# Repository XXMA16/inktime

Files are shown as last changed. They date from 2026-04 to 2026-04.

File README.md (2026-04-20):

# InkTime

## Overview

InkTime is an open-source smartwatch project that aims to provide a customizable and feature-rich wearable device,
powered by the Nordic nRF52840 SoC. The device is designed to be energy-efficient, featuring a 1.54-inch e-ink display,
a 250mAh battery, an IMU for motion tracking, and a haptic driver for tactile feedback.

## Hardware Diagram

Hardware Diagram

## Bill of Materials

| Quantity | Component | Package | Producer / Part | Link | Datasheet |
|---|---|---|---|---|---|
| 1 | SoC | aQFN-73 | Nordic / nRF52840-QIAA | [Link](TODO) | [Datasheet](TODO) |
| 1 | PMIC | BGA-8 | TI / BQ25180YBGR | [Link](TODO) | [Datasheet](TODO) |
| 1 | PMIC | WLCSP-15 | Richtek / RT6160AWSC | [Link](TODO) | [Datasheet](TODO) |
| 1 | Fuel Gauge IC | TDFN-8 | Analog Devices / MAX17048  | [Link](TODO) | [Datasheet](TODO) |
| 1 | ESD Protection IC | SOT-23-6 | ST / USBLC6-2SC6Y | [Link](TODO) | [Datasheet](TODO) |
| 1 | Haptic Driver | BGA-9 | TI / DRV2605YZFR | [Link](TODO) | [Datasheet](TODO) |
| 1 | IMU | 12-pin LGA | Bosch / BMA423 | [Link](TODO) | [Datasheet](TODO) |
| 1 | Antenna | 3216 (1206)  | Johanson / 2.45GHz Antenna | [Link](TODO) | [Datasheet](TODO) |
| 1 | Connector | FPC-24 | Molex / EPD Connector | [Link](TODO) | [Datasheet](TODO) |
| 1 | Connector | SMT | Kinghelm / KH-TYPE-C-16P | [Link](TODO) | [Datasheet](TODO) |
| 3 | Switch | SMT (Button) | Panasonic / Tactile SW | [Link](TODO) | [Datasheet](TODO) |
| 3 | Diode | SOD-123 | ON Semi / MBR0530 | [Link](TODO) | [Datasheet](TODO) |
| 1 | N-MOSFET | SC-70-3 | Vishay / SI1308EDL | [Link](TODO) | [Datasheet](TODO) |
| 1 | P-MOSFET | SOT-23 | Diodes Inc / DMG2305UX-7 | [Link](TODO) | [Datasheet](TODO) |

| Quantity | Component | Value | Package | Producer | Link | Datasheet |
|---|---|---|---|---|---|---|
| 1 | Jumper | - | SMD | - | [Link](TODO) | [Datasheet](TODO) |
| 3 | Resistor  | 0 | 0201 | - | [Link](TODO) | [Datasheet](TODO) |
| 1 | Resistor  | 0.47R | 0201 | - | [Link](TODO) | [Datasheet](TODO) |
| 1 | Resistor  | 2.2R | 0201 | - | [Link](TODO) | [Datasheet](TODO) |
| 2 | Resistor  | 3.3K | 0201 | - | [Link](TODO) | [Datasheet](TODO) |
| 2 | Resistor  | 5.1K | 0201 | - | [Link](TODO) | [Datasheet](TODO) |
| 6 | Resistor  | 10K | 0201 | - | [Link](TODO) | [Datasheet](TODO) |
| 3 | Capacitor | N.C. | 0201 | - | - | ** - |
| 2 | Capacitor | 1pF | 0201 | - | [Link](TODO) | [Datasheet](TODO) |
| 1 | Capacitor | 820pF | 0201 | - | [Link](TODO) | [Datasheet](TODO) |
| 4 | Capacitor | 12pF | 0201 | - | [Link](TODO) | [Datasheet](TODO) |
| 1 | Capacitor | 100pF | 0201 | - | [Link](TODO) | [Datasheet](TODO) |
| 1 | Capacitor | 47nF | 0201 | - | [Link](TODO) | [Datasheet](TODO) |
| 9 | Capacitor | 100nF | 0201 | - | [Link](TODO) | [Datasheet](TODO) |
| 1 | Capacitor | 0.1uF/50V | 0201 | - | [Link](TODO) | [Datasheet](TODO) |
| 7 | Capacitor | 1uF | 0402 | - | [Link](TODO) | [Datasheet](TODO) |
| 9 | Capacitor | 1uF/50V | 0402 | - | [Link](TODO) | [Datasheet](TODO) |
| 5 | Capacitor | 4.7uF | 0402 | - | [Link](TODO) | [Datasheet](TODO) |
| 1 | Capacitor | 4.7uF/25V | 0402 | - | [Link](TODO) | [Datasheet](TODO) |
| 3 | Capacitor | 10uF | 0402 | - | [Link](TODO) | [Datasheet](TODO) |
| 2 | Capacitor | 22uF | 0402 | - | [Link](TODO) | [Datasheet](TODO) |
| 1 | Inductor  | 3.9nH | 0402 | - | [Link](TODO) | [Datasheet](TODO) |
| 1 | Inductor  | 470nH | 1008 | Cjiang | [Link](https://jlcpcb.com/partdetail/6763488-FTC252012SR47MBCA/C5832368) | [Datasheet](https://jlc-prod-smt.oss-eu-central-1.aliyuncs.com/smtDataManualFile/8602848214240948224-C5832368.pdf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) |
| 1 | Inductor  | 10uH | 0402 | - | [Link](TODO) | [Datasheet](TODO) |
| 1 | Inductor  | 15uH | 0402 | - | [Link](TODO) | [Datasheet](TODO) |
| 1 | Inductor  | 68uH | 4848 | Wurth | [Link](TODO) | [Datasheet](https://www.we-online.com/components/products/datasheet/744043003.pdf) |
| 1 | Crystal | 32.768kHz | SMD | Nordic | [Link](TODO) | [Datasheet](TODO) |
| 1 | Crystal | 32MHz | SMD | Nordic | [Link](TODO) | [Datasheet](TODO) |

## SoC pin configuration

- **P$AD22 (SWO)** - connection to TP_SWO for debugging
- **P$AA24 (SWDCLK)** - connection for SWD, for the purpose of clock debugging
- **P$AC24 (SWDIO)** - SWD input/output connection
- **P$AC13 (RESET)** - connection to TP_RESET and SWD for resetting the component
- **P$Y23 (P1.01)** - E-Paper Drive Circuit
- **P$AD12 (EPD_BUSY)** - indicates whether the screen is busy displaying or not
- **P$AD10 (EPD_DC)** - E-Paper Display Data/Command selection for SPI connection
- **P$K2 (EPD_CS)** - E-Paper Display Chip Select (SPI)
- **P$AD12 (EPD_RST)** - E-Paper Display Reset for SPI connection
- **P$P13 (MOSI)** - data for screen SPI connection
- **P$A12 (SCK)** - clock for screen SPI connection
- **P$L1 (SDA)** - I2C data for PMIC, Fuel Gauge, IMU
- **P$M2 (SCL)** - I2C clock for PMIC, Fuel Gauge, IMU
- **P$AD8 (P0.13)** - GPIO for the up button.
- **P$AC9 (P0.14)** - GPIO for the middle button.
- **P$W24 (P1.02)** - GPIO for the down button.
- **P$AD6 (D+)** - positive differential trace to the ESD Protection
- **P$AD4 (D-)** - negative differential trace to the ESD Protection
- **P$AD2 (VBUS)** - connection to the VBUS signal of the USB-C Connector
- **P$U1 (HAPTIC_EN)** - Haptic Driver enable/disable
- **P$T2 (PMIC_INT)** - PMIC LiPo battery interrupt
- **P$N1 (IMU_INT1)** - IMU interrupt
- **P$P2 (IMU_INT2)** - IMU interrupt
- **P\$F2 & P$D2** - 32 kHz clock
- **P\$A23 & P$A24** - 32 MHz clock
- **P$J24 (ALERT)** - Fuel Gauge circuit alert
- **P\$H23 & P$F23** - wireless transmission via the antenna

## PCB Layout

### Stackup

1. Signal and Power
2. Ground Plane
3. Power
4. Signal

Thickness: 1mm

- solder mask: 0.0254mm
- surface finish: Hasl 0.02mm
- copper weight: 1oz
- layers: 0.035mm
- outer dielectrics: 0.128mm
- inner dielectric: 0.5132mm

Via Stitching

- drill: 0.35mm diameter
- spacing: 1.8mm
- offset: 0.6mm from the edge of the board

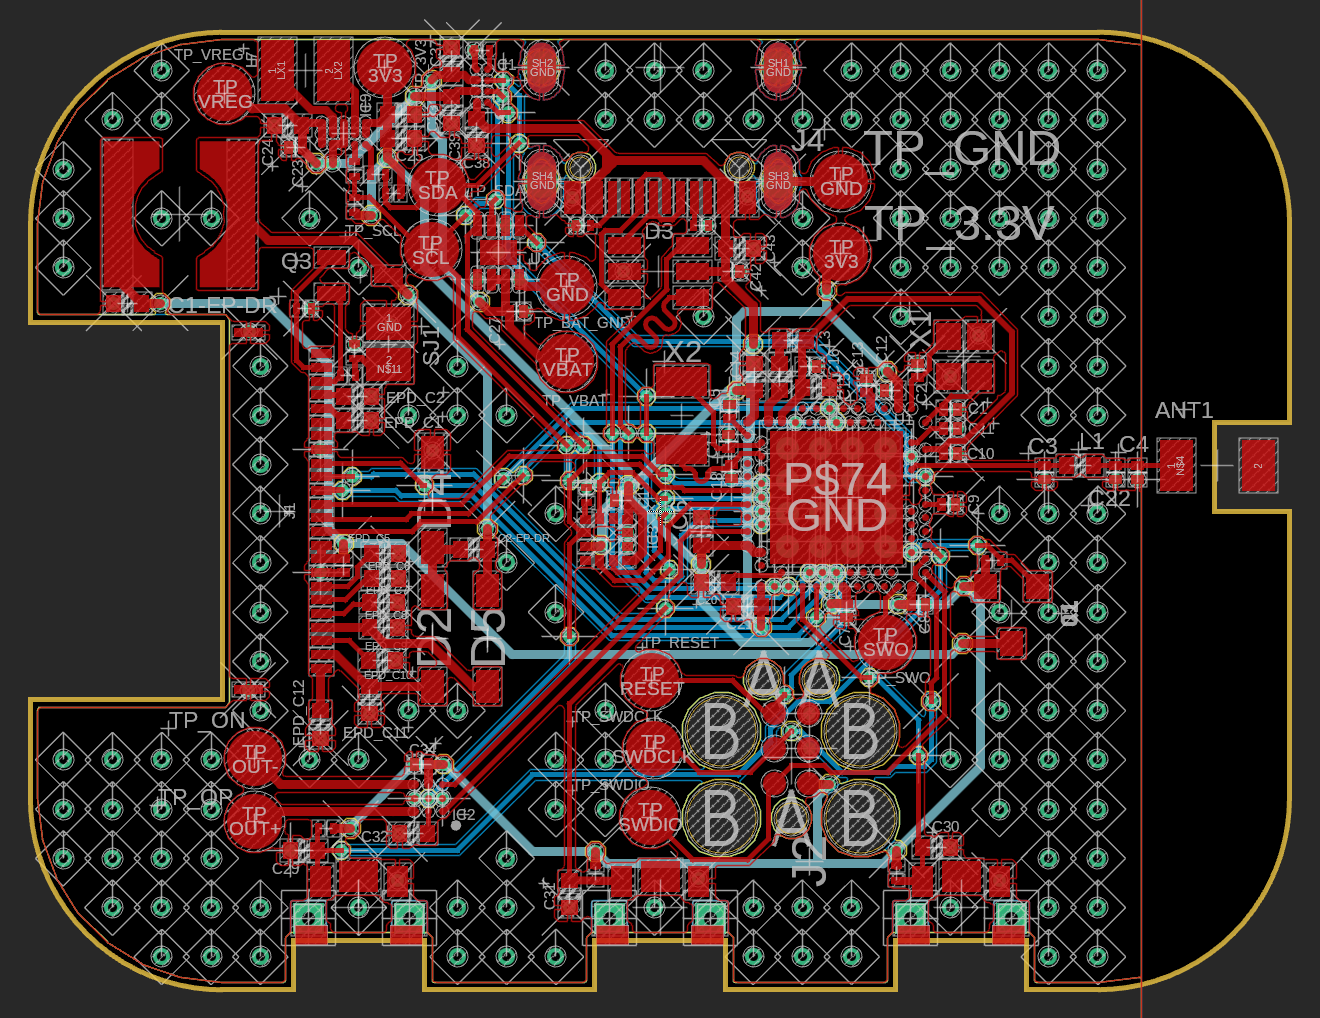
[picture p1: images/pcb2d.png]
PCB Layout


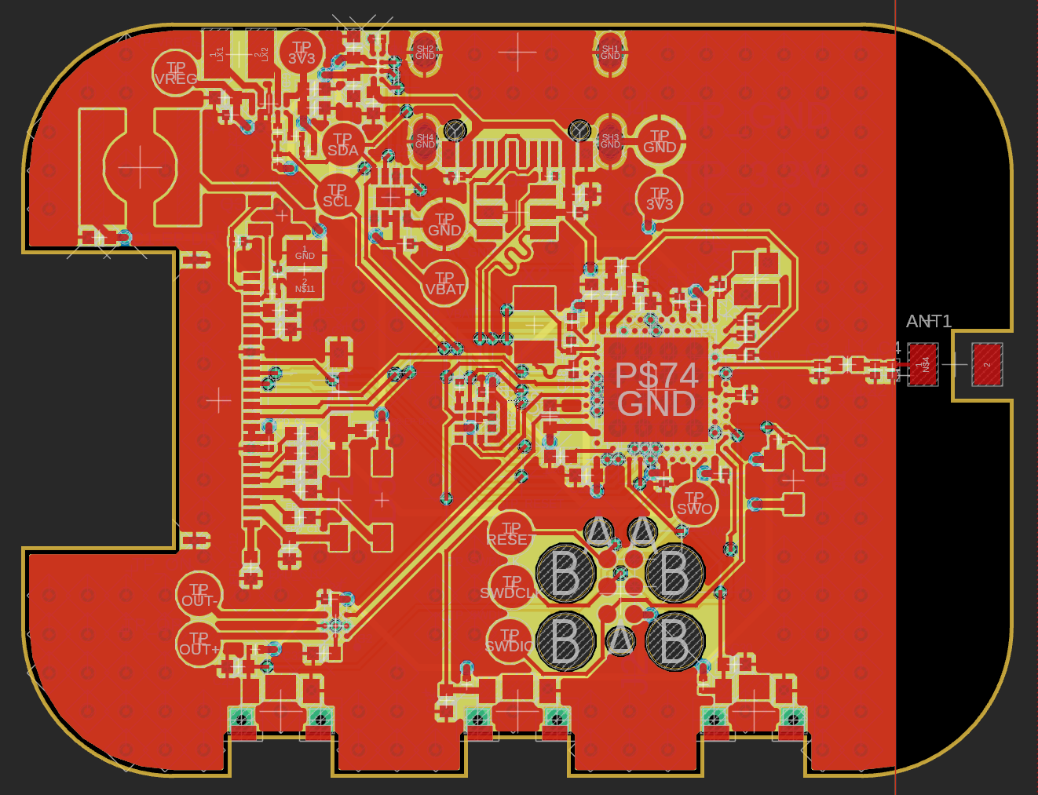
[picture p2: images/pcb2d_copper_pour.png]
PCB Layout Copper Pour


### Component Placement

The **antenna** is placed close to the right edge of the board, with a cutout in the copper pours on the entire right
side of the board. There is also a cutout in the PCB itself under the unconnected pad of the antenna.  
The **PI** network is placed as close as possible to the antenna, an additional capacitor may be placed to better tune
the antenna.  
Light propagates at around half its speed in a vacuum in FR4. A simple calculation gives a value of around:

$$\frac{\lambda}{4} = \frac{c_{FR4}}{4f} \approx \frac{1.4 \times 10^8 m/s}{4 \times 2.4 \times 10^9 Hz} \approx 14.6 mm$$

The trace connecting the PI network to the nRF52840 pin is 5mm long, thus the antenna should work properly.  
It would be better to use a grounded coplanar waveguide for the trace, maybe calculate the width using JLCPCB's online
calculator and use one of their layer stackups instead of the one described above, but this should suffice
for a first iteration of the board.

The decoupling capacitors are placed as possible to the power pins of the IC components and in between the power line
and the pin itself.  
The crystals are also placed close to the pins of the SoC, with the load capacitors traces matched in length and as
short as possible.  
The inductor for the E-Paper Drive Circuit is placed far from any signal lines to avoid interference, even though
it is in a shielded package.

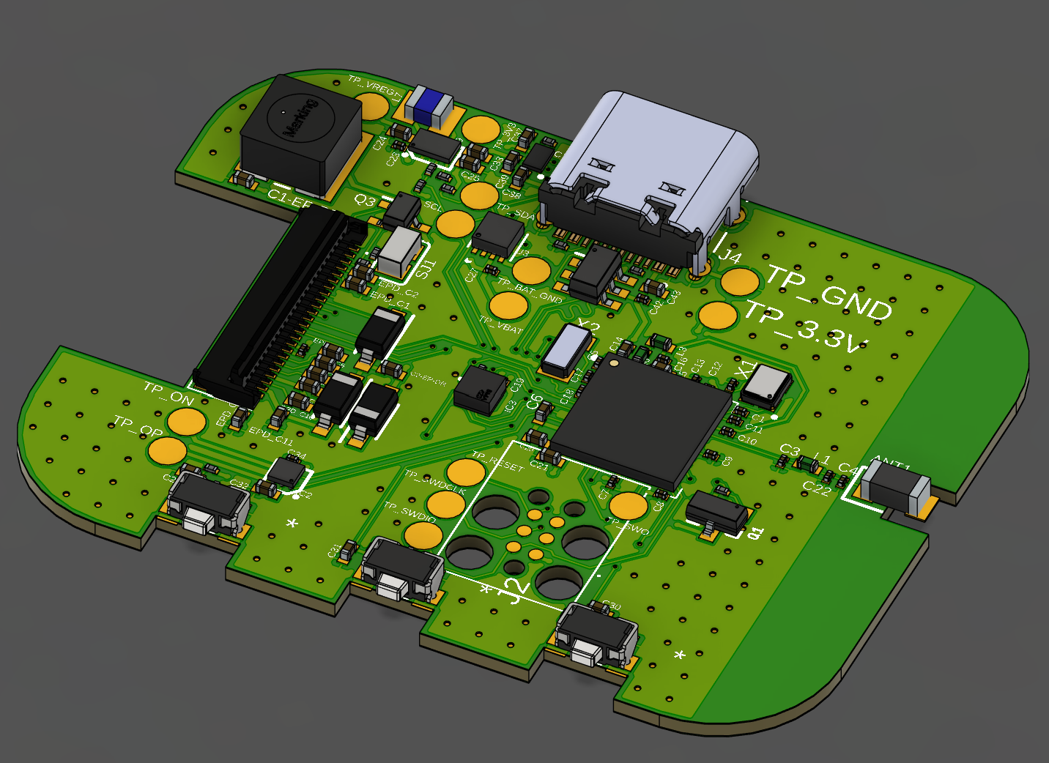
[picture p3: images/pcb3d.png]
PCB 3D Render


### Approved Errors

Most of the errors are related to drill sizes or blind to micro via ratios. These are all approved since, although it
will be more expensive to manufacture, JLCPCB is still able to drill the holes and make the vias.  
Thus these kind of errors can be safely ignored.

Since the nRF52840 is a BGA package, some of the pins *must* have vias in the pad. Some of these cause Fusion to give
a copper clearance error, but, again, JLCPCB is able to manufacture the board so they can also be approved.

## Mechanical Design

The buzzer is placed on the back of the board, in the lower left corner (when worn on the left wrist).

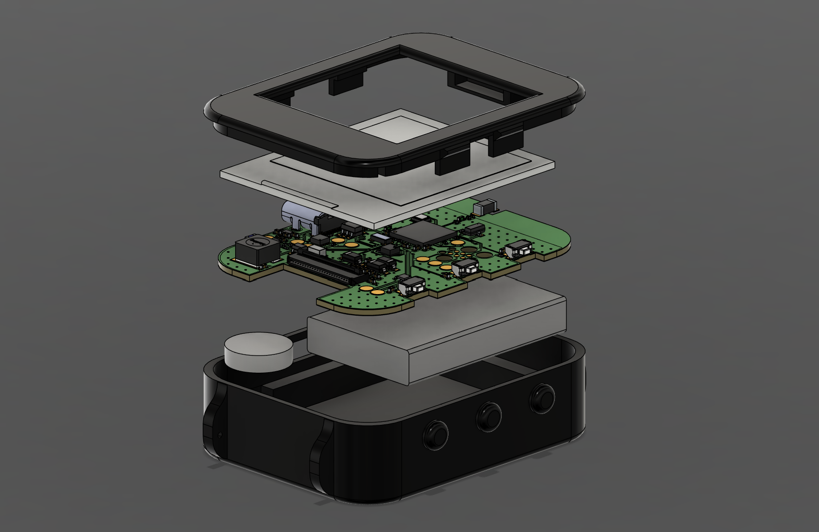
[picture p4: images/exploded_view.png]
exploded view of the smartwatch


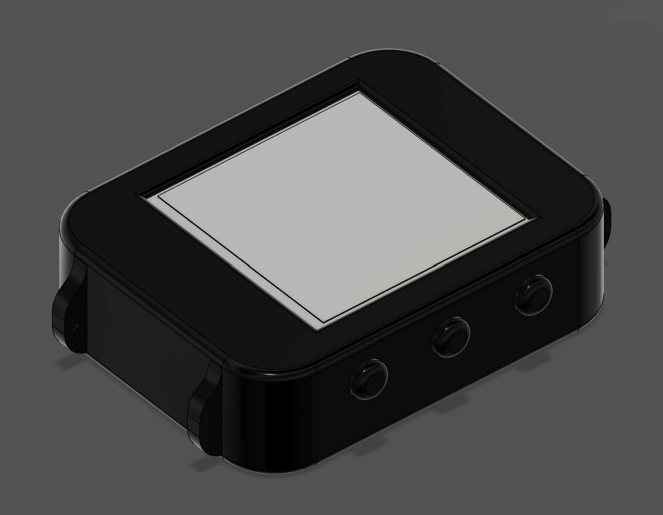
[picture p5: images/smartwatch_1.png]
assembled view 1 of the smartwatch


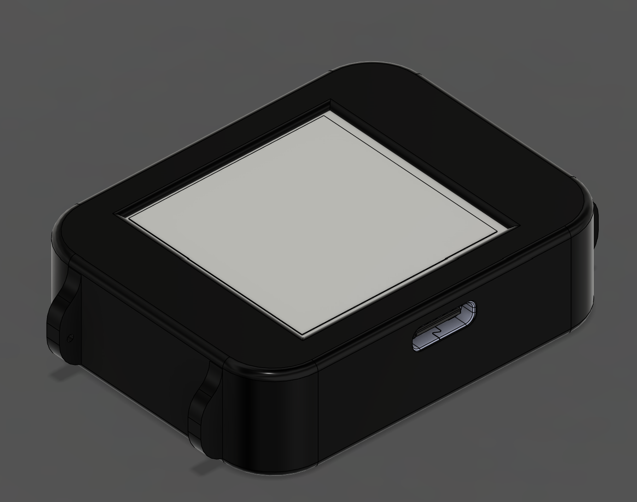
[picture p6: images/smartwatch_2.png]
assembled view 2 of the smartwatch


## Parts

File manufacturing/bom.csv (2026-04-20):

Qty | Value | Device | Package | Parts | Description | ARROW_PART_NUMBER | ARROW_PRICE-STOCK | AVAILABILITY | CHECK_PRICES | COPYRIGHT | DESCRIPTION | DIGI-KEY_PART_NUMBER_1 | DIGI-KEY_PART_NUMBER_2 | DIGI-KEY_PART_NUMBER_3 | HEIGHT | JLCPCB | MANUFACTURER_NAME | MANUFACTURER_PART_NUMBER | MF | MFR_NAME | MOUSER_PART_NUMBER | MOUSER_PRICE-STOCK | MP | PACKAGE | POPULARITY | PRICE | PROD_ID | PURCHASE-URL | SNAPEDA_LINK | TP_SIGNAL_NAME | VALUE
1 |  | ESP32_C6_LIBRARY_7_JUMPER_SJ | ESP32_C6_LIBRARY_7_JUMPER_SJ | SJ1 | SMD solder JUMPER |  |  |  |  |  |  |  |  |  |  |  |  |  |  |  |  |  |  |  | 3
3 | 0 | CPF0201D7K68C1_CPF0201D7K68C1 | CPF0201D7K68C1_0201 | R2, R3, R4 | 7.68k 0201 Thin Film Surface Mount Fixed Resistor +/-0.5% 0.031W CPF0201D7K68C1
1 | 0.1uF/50V | NORDIC_NRF_3_CAPACITOR_0201_L | NORDIC_NRF_3_RESC0201_L | EPD_C5 | Generic chip capacitor
1 | 0.47 | CPF0201D7K68C1_CPF0201D7K68C1 | CPF0201D7K68C1_0201 | R1_EP_DR | 7.68k 0201 Thin Film Surface Mount Fixed Resistor +/-0.5% 0.031W CPF0201D7K68C1
9 | 100nF | NORDIC_NRF_3_CAPACITOR_0201_L | NORDIC_NRF_3_RESC0201_L | C5, C7, C8, C12, C19, C23, C27, C34, C42 | Generic chip capacitor
1 | 100pF | NORDIC_NRF_3_CAPACITOR_0201_L | NORDIC_NRF_3_RESC0201_L | C11 | Generic chip capacitor
6 | 10K | CPF0201D7K68C1_CPF0201D7K68C1 | CPF0201D7K68C1_0201 | R2_EP_DR, R5, R7, R8, R9, R_PWR_EPD | 7.68k 0201 Thin Film Surface Mount Fixed Resistor +/-0.5% 0.031W CPF0201D7K68C1
3 | 10uF | NORDIC_NRF_3_CAPACITOR_0402_L | NORDIC_NRF_3_RESC0402_L | C1-EP-DR, C24, C39 | Generic chip capacitor
1 | 10uH | NORDIC_NRF_2_INDUCTOR_0402_L | NORDIC_NRF_2_RESC0402_L | L2 | Generic chip inductor
4 | 12pF | NORDIC_NRF_3_CAPACITOR_0201_L | NORDIC_NRF_3_RESC0201_L | C1, C2, C17, C18 | Generic chip capacitor
1 | 15uH | NORDIC_NRF_2_INDUCTOR_0402_L | NORDIC_NRF_2_RESC0402_L | L3 | Generic chip inductor
2 | 1pF | NORDIC_NRF_3_CAPACITOR_0201_L | NORDIC_NRF_3_RESC0201_L | C3, C4 | Generic chip capacitor
7 | 1uF | NORDIC_NRF_3_CAPACITOR_0402_L | NORDIC_NRF_3_RESC0402_L | C15, C29, C30, C31, C32, C37, C38 | Generic chip capacitor
9 | 1uF/50V | NORDIC_NRF_3_CAPACITOR_0402_L | NORDIC_NRF_3_RESC0402_L | EPD_C1, EPD_C2, EPD_C6, EPD_C7, EPD_C8, EPD_C9, EPD_C10, EPD_C11, EPD_C12 | Generic chip capacitor
1 | 2.2 | CPF0201D7K68C1_CPF0201D7K68C1 | CPF0201D7K68C1_0201 | R_TYPE_SEL | 7.68k 0201 Thin Film Surface Mount Fixed Resistor +/-0.5% 0.031W CPF0201D7K68C1
3 | 2025-10-22_07-23-44_LIBRARY_EVP-AKE31ASW_EVP-AKE31A_PAN | 2025-10-22_07-23-44_LIBRARY_EVP-AKE31ASW_EVP-AKE31A_PAN | 2025-10-22_07-23-44_LIBRARY_SW_EVP-AKE31A_PAN | SW_DN, SW_ENT, SW_UP |  |  |  |  |  | Copyright (C) 2025 Ultra Librarian. All rights reserved. |  | P123437TR-ND | P123437CT-ND | P123437DKR-ND |  |  | Panasonic | EVP-AKE31A
1 | 20V/4.2A/52mO/1.4W | ESP32_C6_LIBRARY_4_ESP32_WROVER_SPARKFUN-DISCRETESEMI_MOSFET_PCH-DMG2305UX-7 | ESP32_C6_LIBRARY_4_ESP32_C6_LIBRARY_4_ESP32_C6_LIBRARY_4_ESP32_C6_LIBRARY_4_ESP32_WROVER_SPARKFUN-DISCRETESEMI_SOT23-3 | Q1 | P-channel MOSFETs |  |  |  |  |  |  |  |  |  |  |  |  |  |  |  |  |  |  |  |  |  | TRAN-14388 |  |  |  | 20V/4.2A/52mO/1.4W
2 | 22uF | NORDIC_NRF_3_CAPACITOR_0402_L | NORDIC_NRF_3_RESC0402_L | C25, C33 | Generic chip capacitor
1 | 2450AT18B100E | 2450AT18B100E_2450AT18B100E | 2450AT18B100E_ANTC3216X140N | ANT1 | Antennas 2.45GHz ANTENNA | 2450AT18B100E | https://www.arrow.com/en/products/2450at18b100e/johanson-dielectrics?utm_currency=USD&region=nac |  |  |  | Antennas 2.45GHz ANTENNA |  |  |  | 1.4mm |  | JOHANSON TECHNOLOGY | 2450AT18B100E |  |  | 609-2450AT18B100E | https://www.mouser.co.uk/ProductDetail/Johanson-Technology/2450AT18B100E?qs=yCnrNFeXz%252Bh5MFsFIXGZGA%3D%3D
1 | 3.9nH | NORDIC_NRF_2_INDUCTOR_0402_L | NORDIC_NRF_2_RESC0402_L | L1 | Generic chip inductor
1 | 32.768kHz | NORDIC_NRF_1_XTAL_32KHZ | NORDIC_NRF_1_XTAL_3215_N | X2
1 | 32MHz | NORDIC_NRF_XTAL_32MHZ | NORDIC_NRF_BT-XTAL_2016_N | X1
2 | 3K3 | CPF0201D7K68C1_CPF0201D7K68C1 | CPF0201D7K68C1_0201 | R17, R18 | 7.68k 0201 Thin Film Surface Mount Fixed Resistor +/-0.5% 0.031W CPF0201D7K68C1
5 | 4.7uF | NORDIC_NRF_3_CAPACITOR_0402_L | NORDIC_NRF_3_RESC0402_L | C6, C14, C20, C21, C43 | Generic chip capacitor
1 | 4.7uF/25V | NORDIC_NRF_3_CAPACITOR_0402_L | NORDIC_NRF_3_RESC0402_L | C2-EP-DR | Generic chip capacitor
1 | 47nF | NORDIC_NRF_3_CAPACITOR_0201_L | NORDIC_NRF_3_RESC0201_L | C16 | Generic chip capacitor
1 | 503480-2400 | 503480-2400_503480-2400 | 503480-2400_5034802400 | J1 | FFC & FPC Connectors 0.5mm FPC RA SMT Dual Contact 24Ckt |  |  |  |  |  | FFC & FPC Connectors 0.5mm FPC RA SMT Dual Contact 24Ckt |  |  |  | 1.87mm |  | Molex | 503480-2400 |  |  | 538-503480-2400 | https://www.mouser.co.uk/ProductDetail/Molex/503480-2400?qs=OAhjpuo3Vu7efIoxFh9AOw%3D%3D
2 | 5K1 | CPF0201D7K68C1_CPF0201D7K68C1 | CPF0201D7K68C1_0201 | R1_USB, R2_USB | 7.68k 0201 Thin Film Surface Mount Fixed Resistor +/-0.5% 0.031W CPF0201D7K68C1
1 | 68uH | ESP32_C6_LIBRARY_2_744043680IND_4828-WE-TPC_WRE | ESP32_C6_LIBRARY_2_IND_4828-WE-TPC_WRE | L5 |  |  |  |  |  | Copyright (C) 2024 Ultra Librarian. All rights reserved. |  |  |  |  |  |  |  | 744043680 |  | Wurth Electronics
1 | 820pF | NORDIC_NRF_3_CAPACITOR_0201_L | NORDIC_NRF_3_RESC0201_L | C9 | Generic chip capacitor
1 | BMA423 | BMA423_BMA423 | BMA423_BMA423 | IC3 | Accelerometers Triaxial low-g 12bit Acceleration Sensor | BMA423 | https://www.arrow.com/en/products/bma423/bosch |  |  |  | Accelerometers Triaxial low-g 12bit Acceleration Sensor |  |  |  | 1mm |  | BOSCH | BMA423 |  |  | 262-BMA423 | https://www.mouser.co.uk/ProductDetail/Bosch-Sensortec/BMA423?qs=HXFqYaX1Q2xC%252BSgeGoX3mg%3D%3D
1 | BQ25180YBGR | BQ25180YBGR_BQ25180YBGR | BQ25180YBGR_BGA8C40P2X4_100X155X50 | IC1 | Charger IC Lithium Ion/Polymer, Lithium Iron Phosphate 8-DSBGA (1.6x1.1) | BQ25180YBGR | https://www.arrow.com/en/products/bq25180ybgr/texas-instruments?utm_currency=USD&region=nac |  |  |  | Charger IC Lithium Ion/Polymer | Lithium Iron Phosphate 8-DSBGA (1.6x1.1) |  |  |  | 0.5mm |  | Texas Instruments | BQ25180YBGR |  |  | 595-BQ25180YBGR | https://www.mouser.co.uk/ProductDetail/Texas-Instruments/BQ25180YBGR?qs=doiCPypUmgEWjAK%252BJAX6Tw%3D%3D
1 | DRV2605YZFR | DRV2605YZFR_DRV2605YZFR | DRV2605YZFR_BGA9C50P3X3_144X144X62 | IC2 | Haptic Driver for ERM/LRA with Built-In Library and Smart Loop Architecture | DRV2605YZFR | https://www.arrow.com/en/products/drv2605yzfr/texas-instruments?region=nac |  |  |  | Haptic Driver for ERM/LRA with Built-In Library and Smart Loop Architecture |  |  |  | 0.625mm |  | Texas Instruments | DRV2605YZFR
1 | FTC252012SR47MBCA | MLP2016SR47MT0S1_FTC252012SR47MBCA | MLP2016SR47MT0S1_INDC2016X100N | L7 | SMD / SMT Inductors (Coils), L=0.47?H, L x W x T : |  |  |  |  |  | SMD / SMT Inductors (Coils) | L=0.47?H | L x W x T : |  |  |  | 1mm | https://jlcpcb.com/partdetail/6763488-FTC252012SR47MBCA/C5832368 | TDK | FTC252012SR47MBCA
14 | HECTOR_WATCH_1_TPTP20R | HECTOR_WATCH_1_TPTP20R | HECTOR_WATCH_1_TP20R | TP_3.3V, TP_3V3, TP_BAT_GND, TP_GND, TP_ON, TP_OP, TP_RESET, TP_SCL, TP_SDA, TP_SWDCLK, TP_SWDIO, TP_SWO, TP_VBAT, TP_VREG | Test pad |  |  |  |  |  |  |  |  |  |  |  |  |  |  |  |  |  |  |  | 2
1 | KH-TYPE-C-16P | KH-TYPE-C-16P_KH-TYPE-C-16P | KH-TYPE-C-16P_KINGHELM_KH-TYPE-C-16P | J4 | Check availability |  |  | Not in stock | https://www.snapeda.com/parts/KH-TYPE-C-16P/Kinghelm/view-part/?ref=eda |  |  |  |  |  |  |  |  |  | kinghelm |  |  |  | KH-TYPE-C-16P | None |  | None |  |  | https://www.snapeda.com/parts/KH-TYPE-C-16P/Kinghelm/view-part/?ref=snap
1 | MAX17048G+T10 | ESP32_C6_LIBRARY_MAX17048G+T10 | ESP32_C6_LIBRARY_SON50P200X200X80-9N | U3 | Check availability |  |  | In Stock | https://www.snapeda.com/parts/MAX17048G+T10/Analog+Devices/view-part/?ref=eda |  | 3µA 1-Cell/2-Cell Fuel Gauge with ModelGauge |  |  |  |  |  |  |  | Analog Devices |  |  |  | MAX17048G+T10 | TDFN-8 Maxim |  | None |  | https://www.snapeda.com/api/url_track_click_mouser/?unipart_id=329239&manufacturer=Analog Devices&part_name=MAX17048G+T10&search_term=None | https://www.snapeda.com/parts/MAX17048G+T10/Analog+Devices/view-part/?ref=snap
3 | MBR0530 | ESP32_C6_LIBRARY_5_MBR0530SOD | ESP32_C6_LIBRARY_5_SOD3716X135N | D2, D4, D5 | ON SEMICONDUCTOR - MBR0530 - DIODE, SCHOTTKY, 0.5A, 30V, SOD-123
3 | N.C. | NORDIC_NRF_3_CAPACITOR_0201_L | NORDIC_NRF_3_RESC0201_L | C10, C13, C22 | Generic chip capacitor
1 | NRF52840_QF | NORDIC_NRF_4_NRF52840_QF | NORDIC_NRF_4_AQFN50P700X700X85_HS-74N | U1 | nRF52840
1 | RT6160AWSC | RT6160AWSC_RT6160AWSC | RT6160AWSC_BGA15C40P3X5_140X230X60 | IC9 | Buck-Boost Regulator Positive Output Step-Up/Step-Down I2C DC-DC Controller IC 15-WL-CSP (BSC) (1.4x2.3) |  |  |  |  |  | Buck-Boost Regulator Positive Output Step-Up/Step-Down I2C DC-DC Controller IC 15-WL-CSP (BSC) (1.4x2.3) |  |  |  | 0.6mm |  | RICHTEK | RT6160AWSC |  |  | 835-RT6160AWSC | https://www.mouser.co.uk/ProductDetail/Richtek/RT6160AWSC?qs=amGC7iS6iy%2FLd9PSoixZXQ%3D%3D
1 | SI1308EDL-T1-GE3 | ESP32_C6_LIBRARY_6_SI1308EDL-T1-GE3 | ESP32_C6_LIBRARY_6_SOT65P210X110-3N | Q3 | MOSFET N-Ch 30V 1.5A TrenchFET SC70 Vishay Si1308EDL-T1-GE3 N-channel MOSFET Transistor, 1.5 A, 30 V, 3-Pin SC-70 |  |  | In Stock | https://www.snapeda.com/parts/SI1308EDL-T1-GE3/Vishay+Siliconix/view-part/?ref=eda |  | Si1308EDL-T1-GE3 N-channel MOSFET Transistor | 1.5 A | 30 V | 3-Pin SC-70 | Siliconix / Vishay SI1308EDL-T1-GE3 |  |  |  |  |  |  |  | Vishay Siliconix |  |  |  | SI1308EDL-T1-GE3 | SOT-323 Vishay Semiconductor |  | None |  | https://www.snapeda.com/api/url_track_click_mouser/?unipart_id=274603&manufacturer=Vishay Siliconix&part_name=SI1308EDL-T1-GE3&search_term=None
1 | TC2030-IDC | TC2030-IDC_TC2030-IDC | TC2030-IDC_TC2030IDC | J2 | CABLE ADAPTER 6 POS |  |  |  |  |  | CABLE ADAPTER 6 POS |  |  |  | 19mm |  | Tag Connect | TC2030-IDC
1 | USBLC6-2SC6Y | ESP32_C6_LIBRARY_3_USBLC6-2SC6Y | ESP32_C6_LIBRARY_3_SOT95P280X145-6N | D3 | Low Cap. ESD Protection Auto SOT-23-6 STMicroelectronics USBLC6-2SC6Y, Dual Uni-Directional TVS Diode Array, 6-Pin SOT-23 |  |  | In Stock | https://www.snapeda.com/parts/USBLC6-2SC6Y/STMicroelectronics/view-part/?ref=eda |  | 17V Clamp 5A (8/20µs) Ipp Tvs Diode Surface Mount SOT-23-6 |  |  |  |  |  |  |  | STMicroelectronics |  |  |  | USBLC6-2SC6Y | SOT-23-6 STMicroelectronics |  | None |  |  | https://www.snapeda.com/parts/USBLC6-2SC6Y/STMicroelectronics/view-part/?ref=snap

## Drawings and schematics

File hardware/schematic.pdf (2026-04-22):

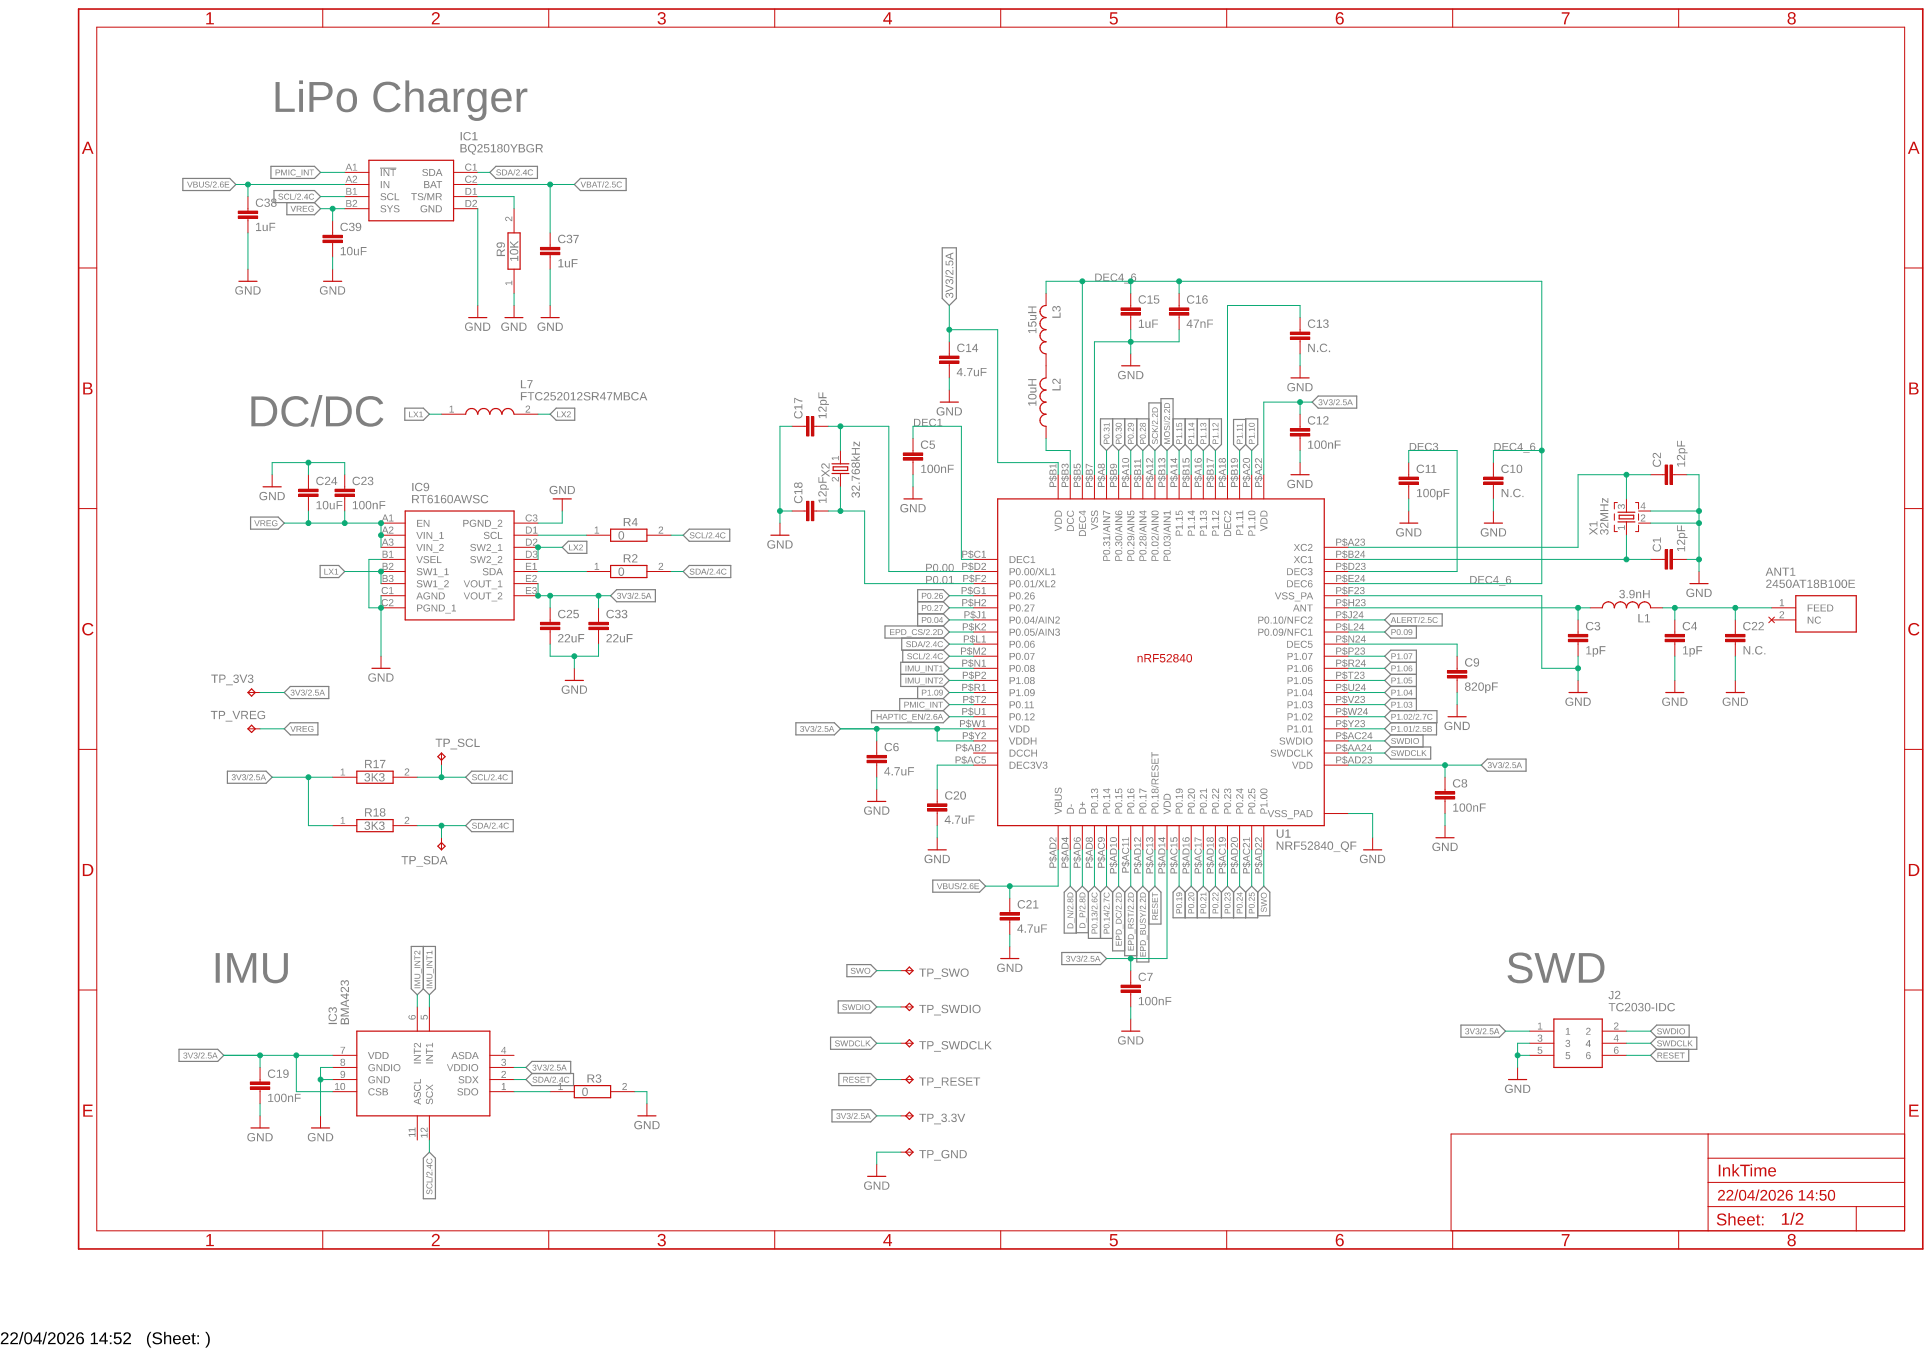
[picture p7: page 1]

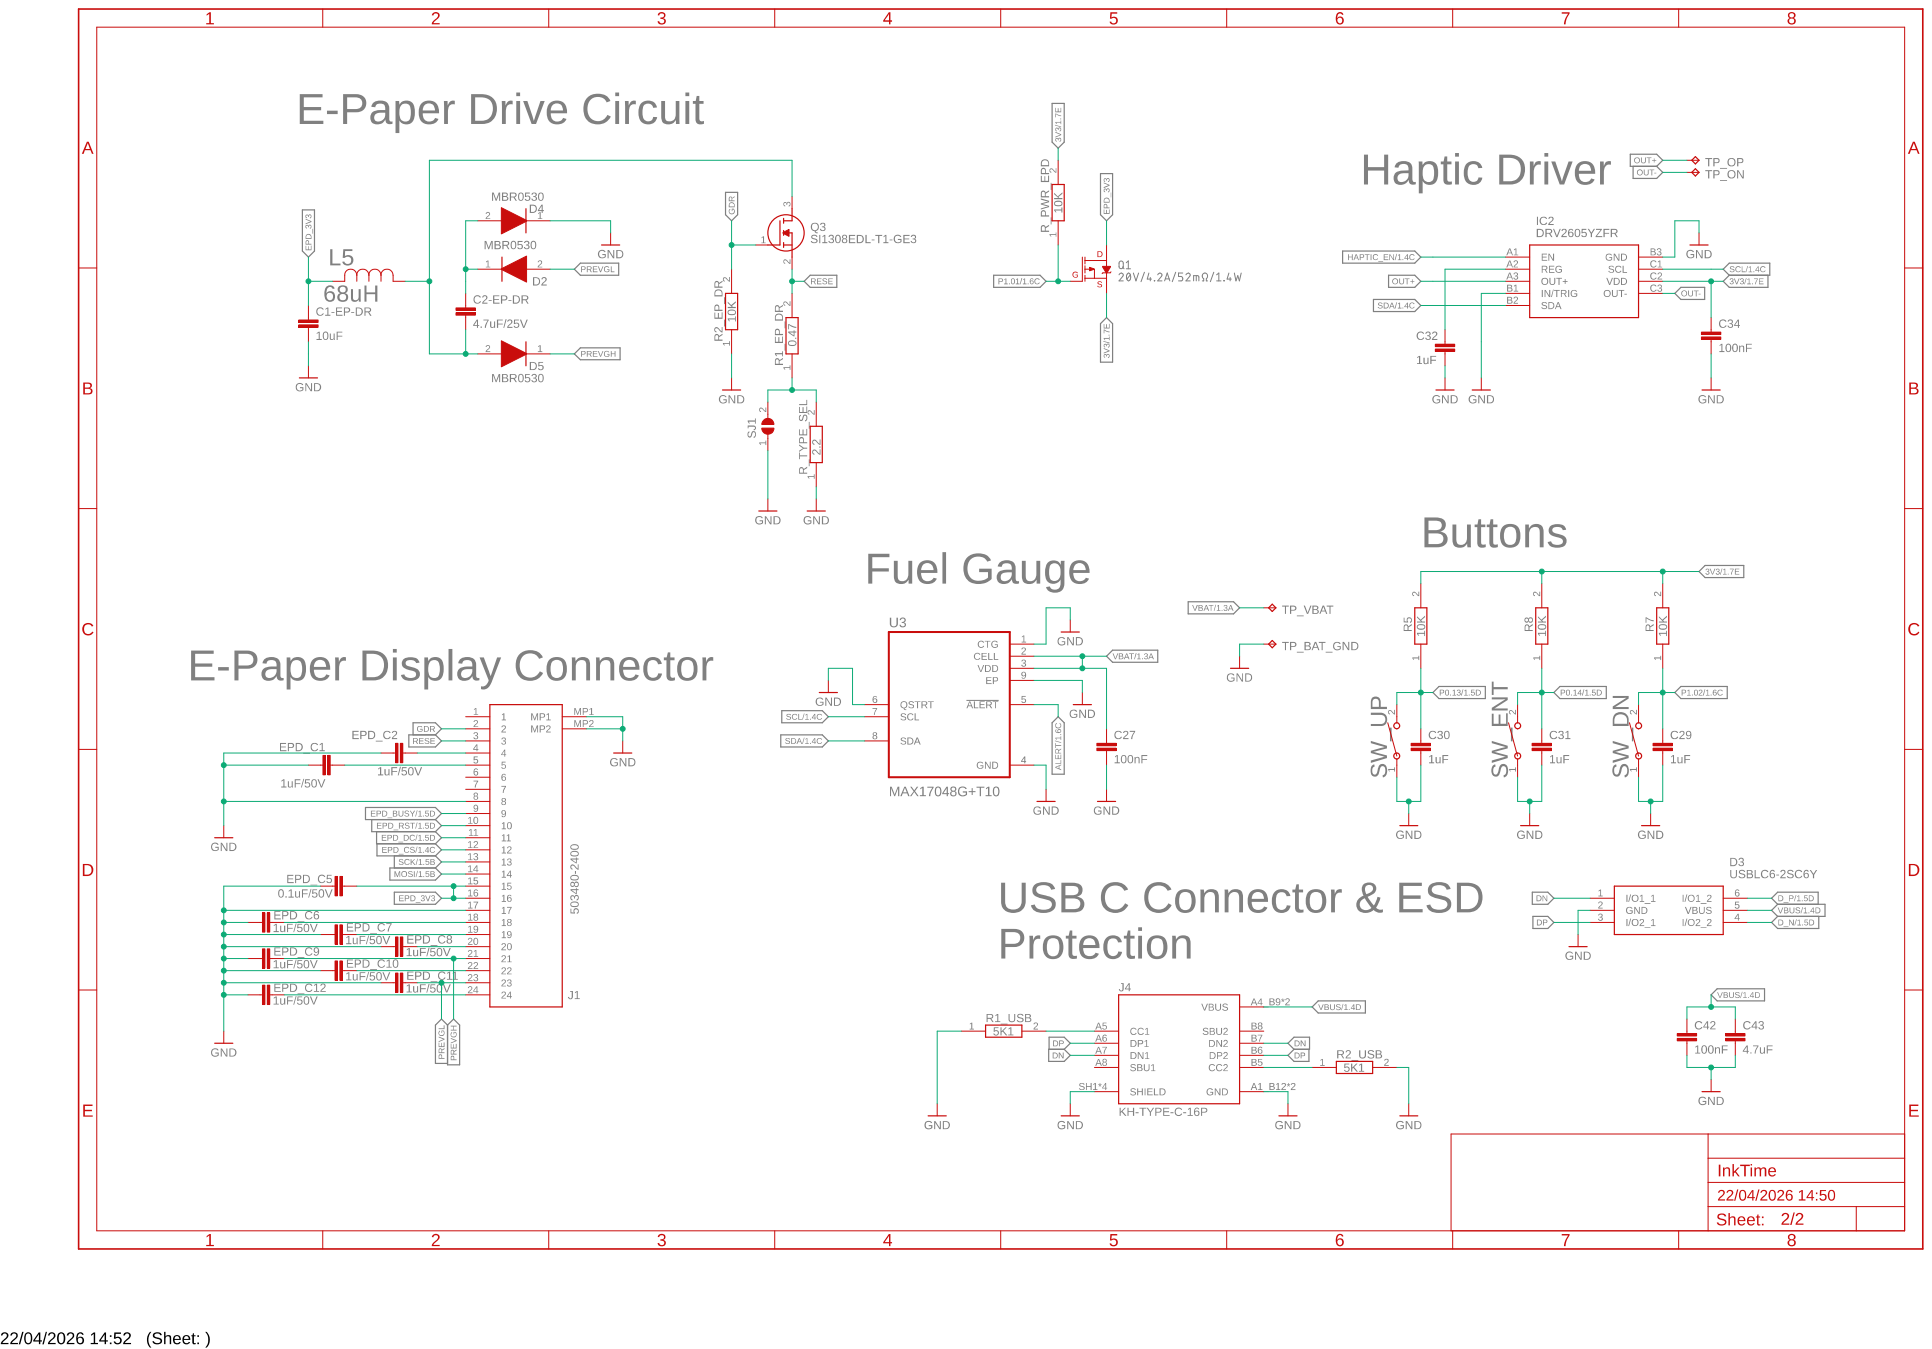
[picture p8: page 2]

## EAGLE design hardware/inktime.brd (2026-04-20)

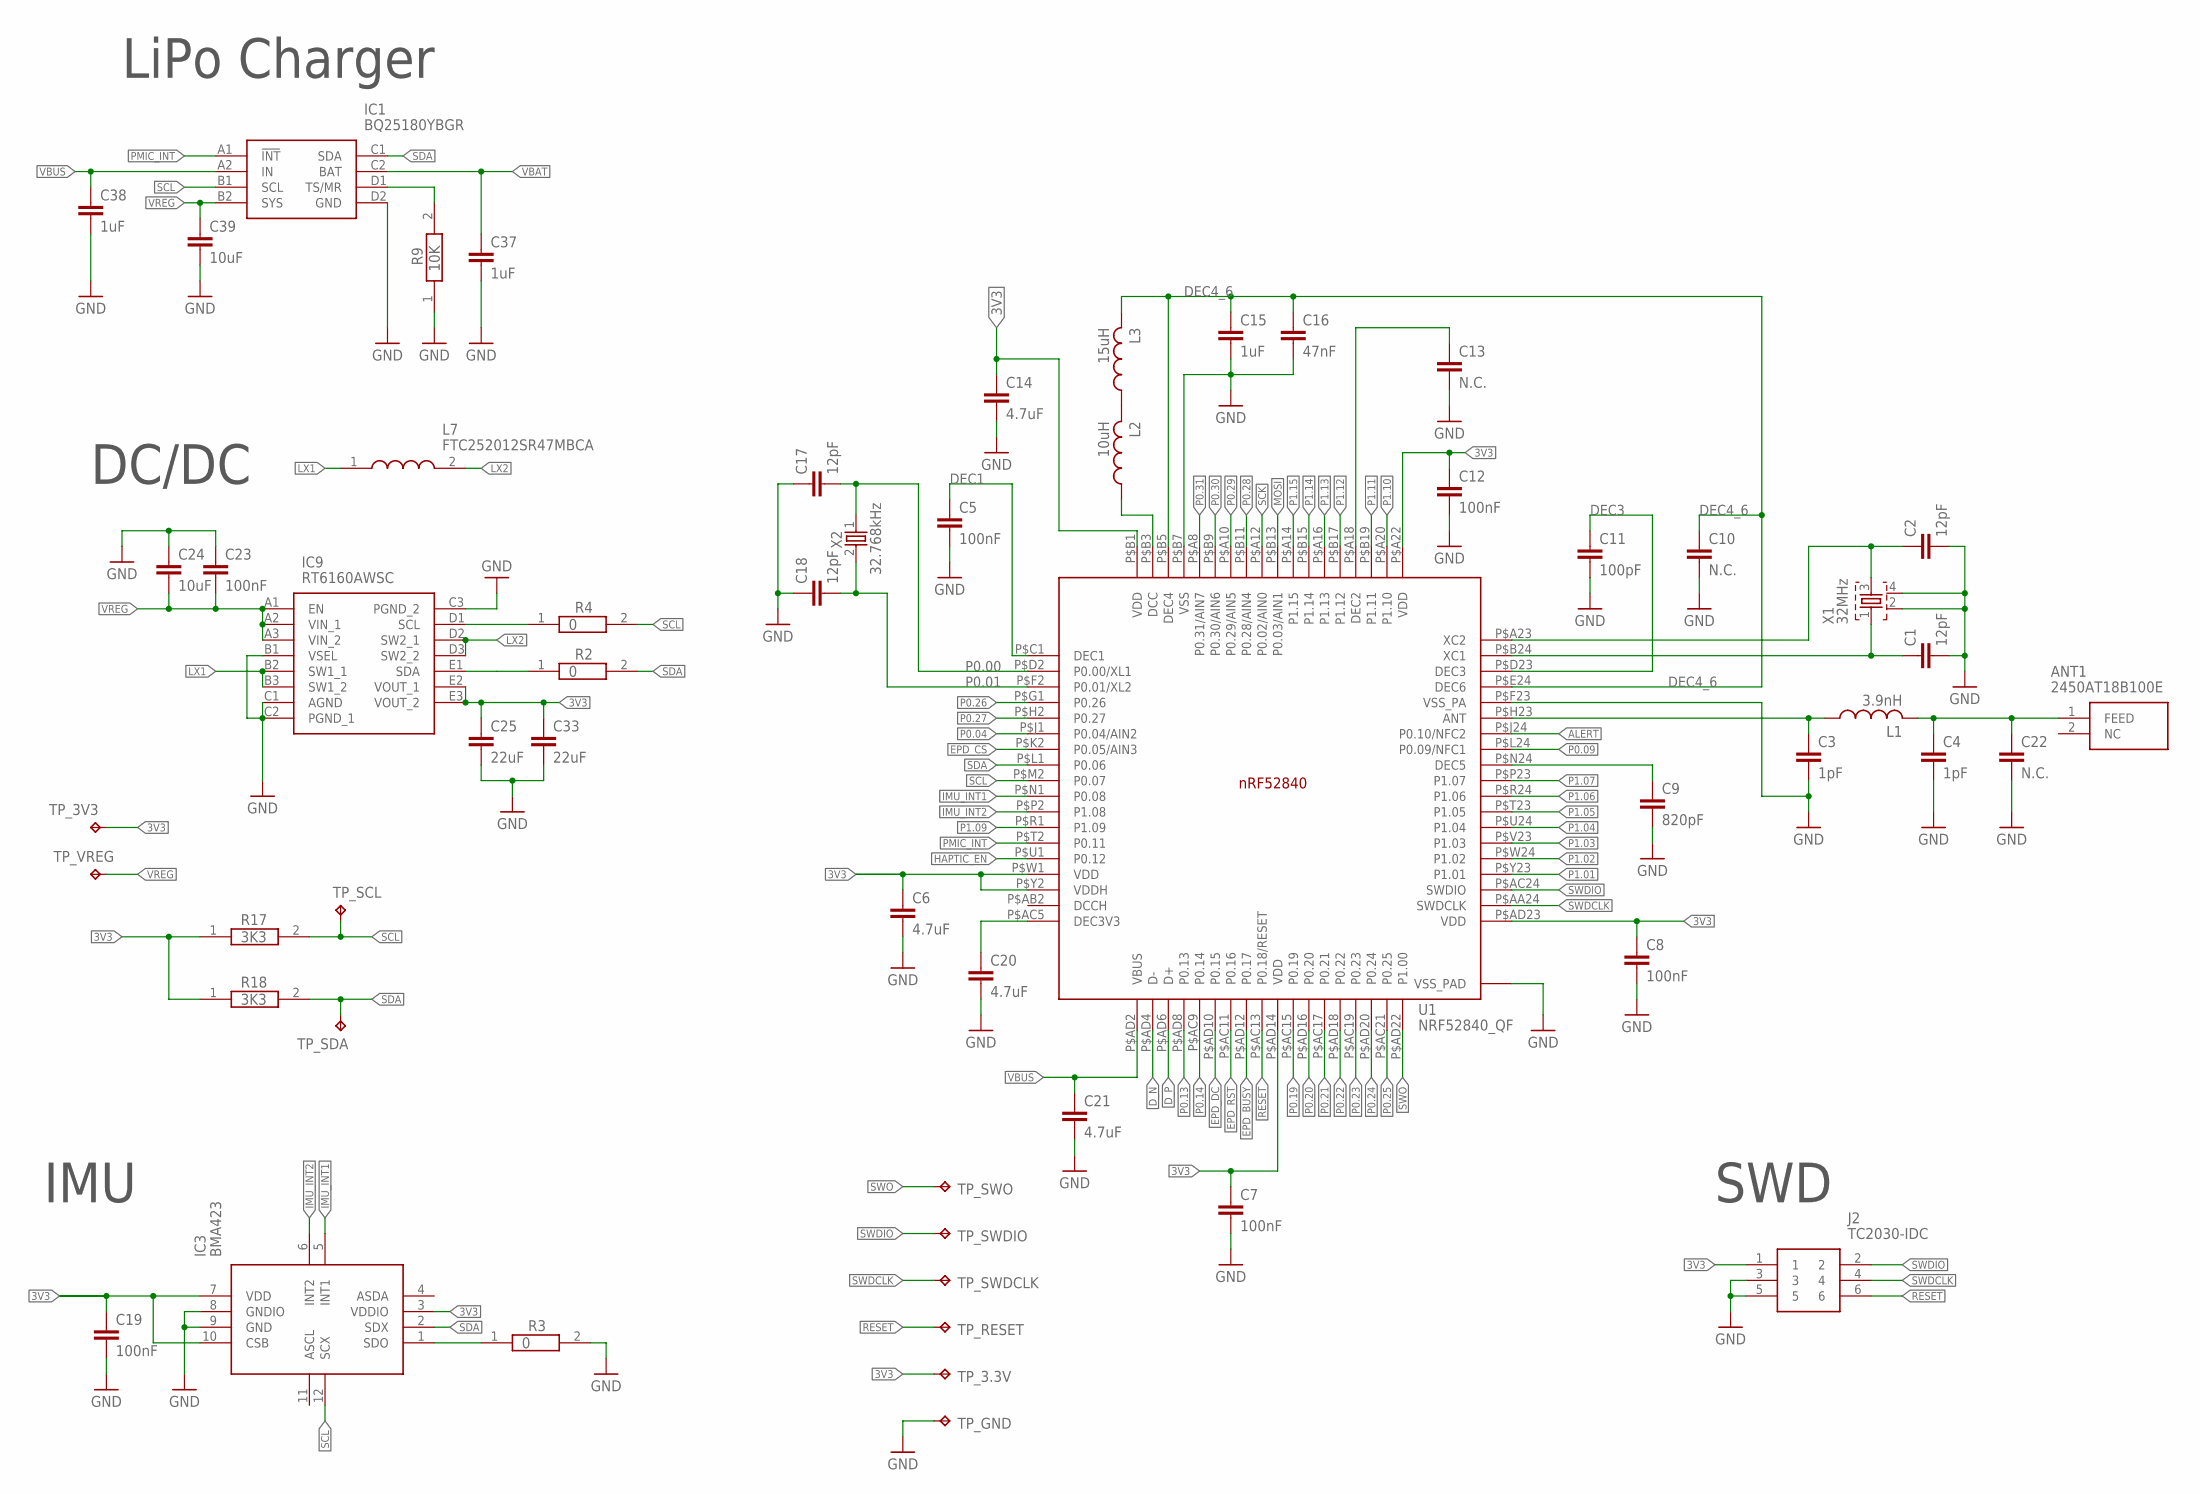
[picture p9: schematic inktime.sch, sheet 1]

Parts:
ANT1: 2450AT18B100E; 2450AT18B100E_ANTC3216X140N
C1, C2, C17, C18: 12pF; NORDIC_NRF_3_RESC0201_L
C3, C4: 1pF; NORDIC_NRF_3_RESC0201_L
C5, C7, C8, C12, C19, C23: 100nF; NORDIC_NRF_3_RESC0201_L
C6, C14, C20, C21: 4.7uF; NORDIC_NRF_3_RESC0402_L
C9: 820pF; NORDIC_NRF_3_RESC0201_L
C10, C13, C22: N.C.; NORDIC_NRF_3_RESC0201_L
C11: 100pF; NORDIC_NRF_3_RESC0201_L
C15, C37, C38: 1uF; NORDIC_NRF_3_RESC0402_L
C16: 47nF; NORDIC_NRF_3_RESC0201_L
C24, C39: 10uF; NORDIC_NRF_3_RESC0402_L
C25, C33: 22uF; NORDIC_NRF_3_RESC0402_L
IC1: BQ25180YBGR; BQ25180YBGR_BGA8C40P2X4_100X155X50
IC3: BMA423; BMA423_BMA423
IC9: RT6160AWSC; RT6160AWSC_BGA15C40P3X5_140X230X60
J2: TC2030-IDC; TC2030-IDC_TC2030IDC
L1: 3.9nH; NORDIC_NRF_2_RESC0402_L
L2: 10uH; NORDIC_NRF_2_RESC0402_L
L3: 15uH; NORDIC_NRF_2_RESC0402_L
L7: FTC252012SR47MBCA; MLP2016SR47MT0S1_INDC2016X100N
R2, R3, R4: 0; CPF0201D7K68C1_0201
R9: 10K; CPF0201D7K68C1_0201
R17, R18: 3K3; CPF0201D7K68C1_0201
TP_3.3V, TP_3V3: HECTOR_WATCH_1_TPTP20R; HECTOR_WATCH_1_TP20R
TP_GND: HECTOR_WATCH_1_TPTP20R; HECTOR_WATCH_1_TP20R
TP_RESET: HECTOR_WATCH_1_TPTP20R; HECTOR_WATCH_1_TP20R
TP_SCL: HECTOR_WATCH_1_TPTP20R; HECTOR_WATCH_1_TP20R
TP_SDA: HECTOR_WATCH_1_TPTP20R; HECTOR_WATCH_1_TP20R
TP_SWDCLK: HECTOR_WATCH_1_TPTP20R; HECTOR_WATCH_1_TP20R
TP_SWDIO: HECTOR_WATCH_1_TPTP20R; HECTOR_WATCH_1_TP20R
TP_SWO: HECTOR_WATCH_1_TPTP20R; HECTOR_WATCH_1_TP20R
TP_VREG: HECTOR_WATCH_1_TPTP20R; HECTOR_WATCH_1_TP20R
U1: NRF52840_QF; NORDIC_NRF_4_AQFN50P700X700X85_HS-74N
X1: 32MHz; NORDIC_NRF_BT-XTAL_2016_N
X2: 32.768kHz; NORDIC_NRF_1_XTAL_3215_N

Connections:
3V3: C6.1, C7.1, C8.1, C12.1, C14.1, C19.1, C25.1, C33.1, IC3.3 (VDDIO), IC3.7 (VDD), IC3.10 (CSB), IC9.E2 (VOUT_1), IC9.E3 (VOUT_2), J2.1, R17.1, R18.1, TP_3.3V.TP, TP_3V3.TP, U1.P$A22 (VDD), U1.P$AD14 (VDD), U1.P$AD23 (VDD), U1.P$B1 (VDD), U1.P$W1 (VDD), U1.P$Y2 (VDDH); also elsewhere on the board
ALERT: U1.P$J24 (P0.10/NFC2); also elsewhere on the board
DEC1: C5.1, U1.P$C1 (DEC1)
DEC3: C11.1, U1.P$D23 (DEC3)
DEC4_6: C10.1, C15.1, C16.1, L3.2, U1.P$B5 (DEC4), U1.P$E24 (DEC6)
D_N: U1.P$AD4 (D-); also elsewhere on the board
D_P: U1.P$AD6 (D+); also elsewhere on the board
EPD_BUSY: U1.P$AD12 (P0.17); also elsewhere on the board
EPD_CS: U1.P$K2 (P0.05/AIN3); also elsewhere on the board
EPD_DC: U1.P$AD10 (P0.15); also elsewhere on the board
EPD_RST: U1.P$AC11 (P0.16); also elsewhere on the board
GND: C1.2, C2.2, C3.2, C4.2, C5.2, C6.2, C7.2, C8.2, C9.2, C10.2, C11.2, C12.2, C13.2, C14.2, C15.2, C16.2, C17.1, C18.1, C19.2, C20.2, C21.2, C22.2, C23.1, C24.1, C25.2, C33.2, C37.2, C38.2, C39.2, IC1.D2 (GND), IC3.8 (GNDIO), IC3.9 (GND), IC9.B1 (VSEL), IC9.C1 (AGND), IC9.C2 (PGND_1), IC9.C3 (PGND_2), J2.3, J2.5, R3.2, R9.1, TP_GND.TP, U1.P$74 (VSS_PAD), U1.P$75 (VSS_PAD), U1.P$76 (VSS_PAD), U1.P$77 (VSS_PAD), U1.P$78 (VSS_PAD), U1.P$79 (VSS_PAD), U1.P$80 (VSS_PAD), U1.P$81 (VSS_PAD), U1.P$82 (VSS_PAD), U1.P$83 (VSS_PAD), U1.P$84 (VSS_PAD), U1.P$85 (VSS_PAD), U1.P$86 (VSS_PAD), U1.P$87 (VSS_PAD), U1.P$88 (VSS_PAD), U1.P$89 (VSS_PAD), U1.P$90 (VSS_PAD), U1.P$B7 (VSS), U1.P$F23 (VSS_PA), X1.2, X1.4; also elsewhere on the board
HAPTIC_EN: U1.P$U1 (P0.12); also elsewhere on the board
IMU_INT1: IC3.5 (INT1), U1.P$N1 (P0.08)
IMU_INT2: IC3.6 (INT2), U1.P$P2 (P1.08)
LX1: IC9.B2 (SW1_1), IC9.B3 (SW1_2), L7.1
LX2: IC9.D2 (SW2_1), IC9.D3 (SW2_2), L7.2
MOSI: U1.P$B13 (P0.03/AIN1); also elsewhere on the board
unnamed: IC1.D1 (TS/MR), R9.2
unnamed: ANT1.1 (FEED), C4.1, C22.1, L1.2
unnamed: C2.1, U1.P$A23 (XC2), X1.3
unnamed: C1.1, U1.P$B24 (XC1), X1.1
unnamed: IC9.E1 (SDA), R2.1
unnamed: IC9.D1 (SCL), R4.1
unnamed: C13.1, U1.P$A18 (DEC2)
unnamed: IC3.1 (SDO), R3.1
unnamed: C20.1, U1.P$AC5 (DEC3V3)
unnamed: L2.1, U1.P$B3 (DCC)
unnamed: L2.2, L3.1
unnamed: C9.1, U1.P$N24 (DEC5)
unnamed: C3.1, L1.1, U1.P$H23 (ANT)
P0.00: C17.2, U1.P$D2 (P0.00/XL1), X2.1
P0.01: C18.2, U1.P$F2 (P0.01/XL2), X2.2
P0.04: U1.P$J1 (P0.04/AIN2)
P0.09: U1.P$L24 (P0.09/NFC1)
P0.13: U1.P$AD8 (P0.13); also elsewhere on the board
P0.14: U1.P$AC9 (P0.14); also elsewhere on the board
P0.19: U1.P$AC15 (P0.19)
P0.20: U1.P$AD16 (P0.20)
P0.21: U1.P$AC17 (P0.21)
P0.22: U1.P$AD18 (P0.22)
P0.23: U1.P$AC19 (P0.23)
P0.24: U1.P$AD20 (P0.24)
P0.25: U1.P$AC21 (P0.25)
P0.26: U1.P$G1 (P0.26)
P0.27: U1.P$H2 (P0.27)
P0.28: U1.P$B11 (P0.28/AIN4)
P0.29: U1.P$A10 (P0.29/AIN5)
P0.30: U1.P$B9 (P0.30/AIN6)
P0.31: U1.P$A8 (P0.31/AIN7)
P1.01: U1.P$Y23 (P1.01); also elsewhere on the board
P1.02: U1.P$W24 (P1.02); also elsewhere on the board
P1.03: U1.P$V23 (P1.03)
P1.04: U1.P$U24 (P1.04)
P1.05: U1.P$T23 (P1.05)
P1.06: U1.P$R24 (P1.06)
P1.07: U1.P$P23 (P1.07)
P1.09: U1.P$R1 (P1.09)
P1.10: U1.P$A20 (P1.10)
P1.11: U1.P$B19 (P1.11)
P1.12: U1.P$B17 (P1.12)
P1.13: U1.P$A16 (P1.13)
P1.14: U1.P$B15 (P1.14)
P1.15: U1.P$A14 (P1.15)
PMIC_INT: IC1.A1 (!INT), U1.P$T2 (P0.11)
RESET: J2.6, TP_RESET.TP, U1.P$AC13 (P0.18/RESET)
SCK: U1.P$A12 (P0.02/AIN0); also elsewhere on the board
SCL: IC1.B1 (SCL), IC3.12 (SCX), R4.2, R17.2, TP_SCL.TP, U1.P$M2 (P0.07); also elsewhere on the board
SDA: IC1.C1 (SDA), IC3.2 (SDX), R2.2, R18.2, TP_SDA.TP, U1.P$L1 (P0.06); also elsewhere on the board
SWDCLK: J2.4, TP_SWDCLK.TP, U1.P$AA24 (SWDCLK)
SWDIO: J2.2, TP_SWDIO.TP, U1.P$AC24 (SWDIO)
SWO: TP_SWO.TP, U1.P$AD22 (P1.00)
VBAT: C37.1, IC1.C2 (BAT); also elsewhere on the board
VBUS: C21.1, C38.1, IC1.A2 (IN), U1.P$AD2 (VBUS); also elsewhere on the board
VREG: C23.2, C24.2, C39.1, IC1.B2 (SYS), IC9.A1 (EN), IC9.A2 (VIN_1), IC9.A3 (VIN_2), TP_VREG.TP

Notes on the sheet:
LiPo Charger
DC/DC
IMU
SWD

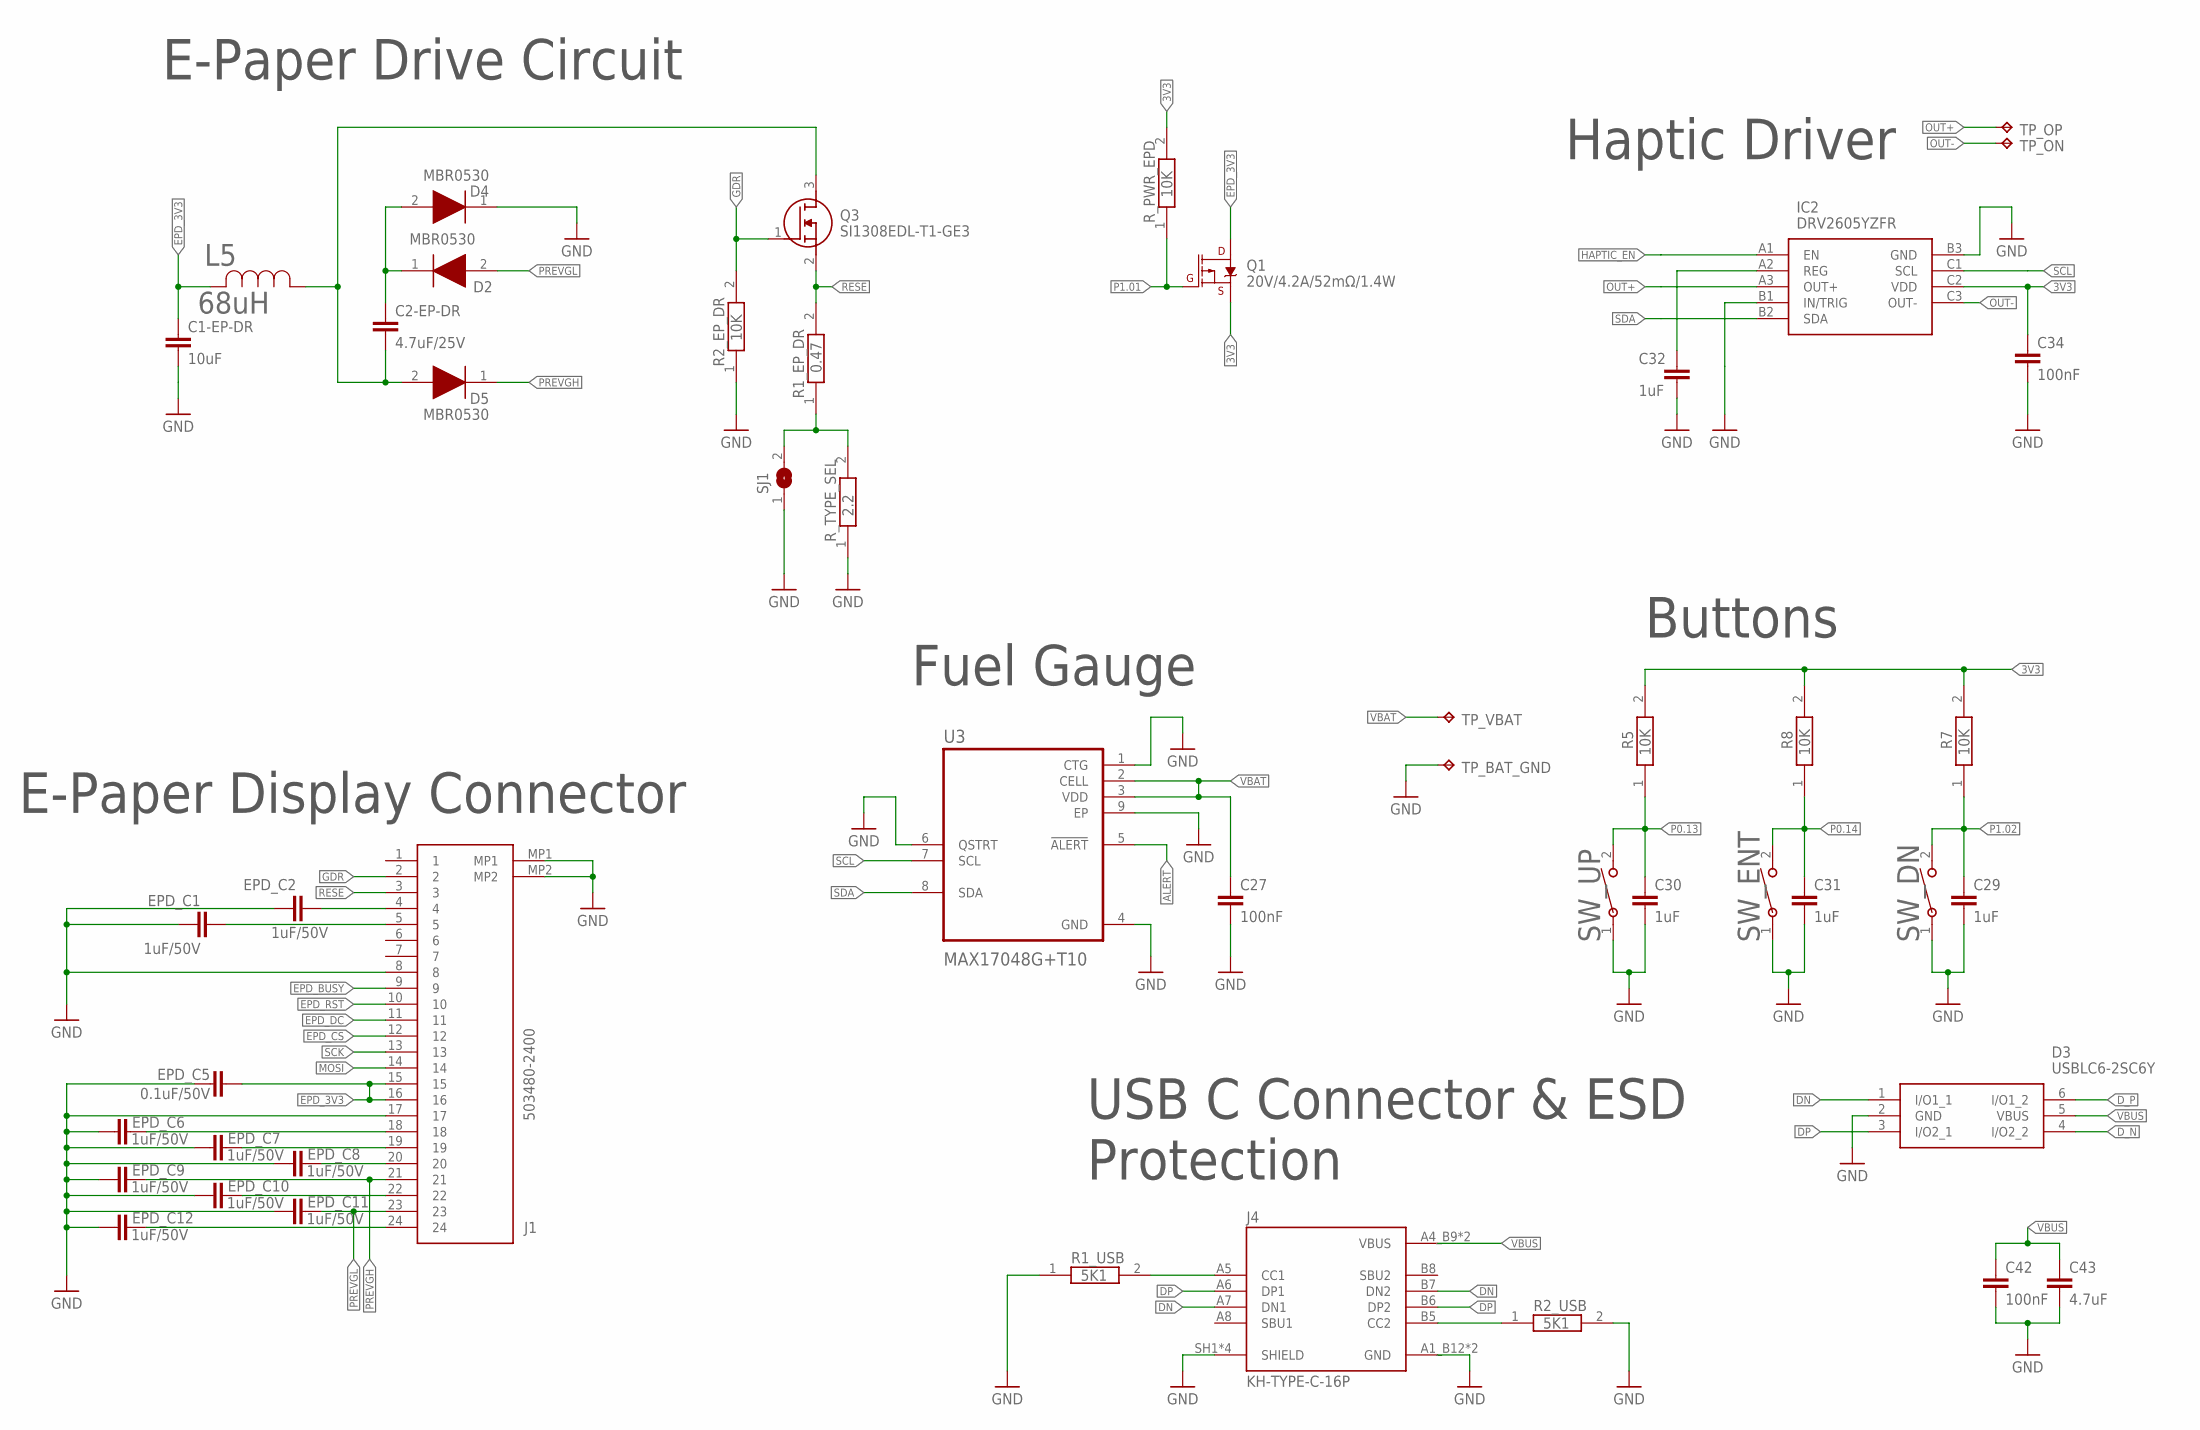
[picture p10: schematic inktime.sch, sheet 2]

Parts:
C1-EP-DR: 10uF; NORDIC_NRF_3_RESC0402_L
C2-EP-DR: 4.7uF/25V; NORDIC_NRF_3_RESC0402_L
C27, C34, C42: 100nF; NORDIC_NRF_3_RESC0201_L
C29, C30, C31, C32: 1uF; NORDIC_NRF_3_RESC0402_L
C43: 4.7uF; NORDIC_NRF_3_RESC0402_L
D2, D4, D5: MBR0530; ESP32_C6_LIBRARY_5_SOD3716X135N
D3: USBLC6-2SC6Y; ESP32_C6_LIBRARY_3_SOT95P280X145-6N
EPD_C1, EPD_C2, EPD_C6, EPD_C7, EPD_C8, EPD_C9, EPD_C10, EPD_C11, EPD_C12: 1uF/50V; NORDIC_NRF_3_RESC0402_L
EPD_C5: 0.1uF/50V; NORDIC_NRF_3_RESC0201_L
IC2: DRV2605YZFR; DRV2605YZFR_BGA9C50P3X3_144X144X62
J1: 503480-2400; 503480-2400_5034802400
J4: KH-TYPE-C-16P; KH-TYPE-C-16P_KINGHELM_KH-TYPE-C-16P
L5: 68uH; ESP32_C6_LIBRARY_2_IND_4828-WE-TPC_WRE
Q1: 20V/4.2A/52mΩ/1.4W; ESP32_C6_LIBRARY_4_ESP32_C6_LIBRARY_4_ESP32_C6_LIBRARY_4_ES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
Q3: SI1308EDL-T1-GE3; ESP32_C6_LIBRARY_6_SOT65P210X110-3N
R1_EP_DR: 0.47; CPF0201D7K68C1_0201
R1_USB, R2_USB: 5K1; CPF0201D7K68C1_0201
R2_EP_DR, R5, R7, R8: 10K; CPF0201D7K68C1_0201
R_PWR_EPD: 10K; CPF0201D7K68C1_0201
R_TYPE_SEL: 2.2; CPF0201D7K68C1_0201
SJ1: ESP32_C6_LIBRARY_7_JUMPER_SJ
SW_DN: 2025-10-22_07-23-44_LIBRARY_EVP-AKE31ASW_EVP-AKE3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; 2025-10-22_07-23-44_LIBRARY_SW_EVP-AKE31A_PAN
SW_ENT: 2025-10-22_07-23-44_LIBRARY_EVP-AKE31ASW_EVP-AKE3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; 2025-10-22_07-23-44_LIBRARY_SW_EVP-AKE31A_PAN
SW_UP: 2025-10-22_07-23-44_LIBRARY_EVP-AKE31ASW_EVP-AKE3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; 2025-10-22_07-23-44_LIBRARY_SW_EVP-AKE31A_PAN
TP_BAT_GND: HECTOR_WATCH_1_TPTP20R; HECTOR_WATCH_1_TP20R
TP_ON: HECTOR_WATCH_1_TPTP20R; HECTOR_WATCH_1_TP20R
TP_OP: HECTOR_WATCH_1_TPTP20R; HECTOR_WATCH_1_TP20R
TP_VBAT: HECTOR_WATCH_1_TPTP20R; HECTOR_WATCH_1_TP20R
U3: MAX17048G+T10; ESP32_C6_LIBRARY_SON50P200X200X80-9N

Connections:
3V3: C34.1, IC2.C2 (VDD), Q1.2 (S), R5.2, R7.2, R8.2, R_PWR_EPD.2; also elsewhere on the board
ALERT: U3.5 (!ALERT); also elsewhere on the board
DN: D3.1 (I/O1_1), J4.A7 (DN1), J4.B7 (DN2)
DP: D3.3 (I/O2_1), J4.A6 (DP1), J4.B6 (DP2)
D_N: D3.4 (I/O2_2); also elsewhere on the board
D_P: D3.6 (I/O1_2); also elsewhere on the board
EPD_3V3: C1-EP-DR.1, EPD_C5.2, J1.15, J1.16, L5.2, Q1.3 (D)
EPD_BUSY: J1.9; also elsewhere on the board
EPD_CS: J1.12; also elsewhere on the board
EPD_DC: J1.11; also elsewhere on the board
EPD_RST: J1.10; also elsewhere on the board
GDR: J1.2, Q3.1 (G), R2_EP_DR.2
GND: C1-EP-DR.2, C27.2, C29.2, C30.2, C31.2, C32.2, C34.2, C42.2, C43.2, D3.2 (GND), D4.1 (K), EPD_C1.1, EPD_C2.1, EPD_C5.1, EPD_C6.1, EPD_C7.1, EPD_C8.1, EPD_C9.1, EPD_C10.1, EPD_C11.1, EPD_C12.1, IC2.B1 (IN/TRIG), IC2.B3 (GND), J1.8, J1.17, J1.MP1, J1.MP2, J4.A1_B12 (GND), J4.A12_B1 (GND), J4.SH1 (SHIELD), J4.SH2 (SHIELD), J4.SH3 (SHIELD), J4.SH4 (SHIELD), R1_USB.1, R2_EP_DR.1, R2_USB.2, R_TYPE_SEL.1, SJ1.1, SW_DN.1, SW_ENT.1, SW_UP.1, TP_BAT_GND.TP, U3.1 (CTG), U3.4 (GND), U3.6 (QSTRT), U3.9 (EP); also elsewhere on the board
HAPTIC_EN: IC2.A1 (EN); also elsewhere on the board
MOSI: J1.14; also elsewhere on the board
unnamed: EPD_C2.2, J1.4
unnamed: C2-EP-DR.1, D2.1 (K), D4.2 (A)
unnamed: C2-EP-DR.2, D5.2 (A), L5.1, Q3.3 (D)
unnamed: EPD_C1.2, J1.5
unnamed: R1_EP_DR.1, R_TYPE_SEL.2, SJ1.2
unnamed: EPD_C6.2, J1.18
unnamed: EPD_C7.2, J1.19
unnamed: EPD_C8.2, J1.20
unnamed: EPD_C10.2, J1.22
unnamed: C32.1, IC2.A2 (REG)
unnamed: EPD_C12.2, J1.24
unnamed: J4.B5 (CC2), R2_USB.1
unnamed: J4.A5 (CC1), R1_USB.2
OUT+: IC2.A3 (OUT+), TP_OP.TP
OUT-: IC2.C3 (OUT-), TP_ON.TP
P0.13: C30.1, R5.1, SW_UP.2; also elsewhere on the board
P0.14: C31.1, R8.1, SW_ENT.2; also elsewhere on the board
P1.01: Q1.1 (G), R_PWR_EPD.1; also elsewhere on the board
P1.02: C29.1, R7.1, SW_DN.2; also elsewhere on the board
PREVGH: D5.1 (K), EPD_C9.2, J1.21
PREVGL: D2.2 (A), EPD_C11.2, J1.23
RESE: J1.3, Q3.2 (S), R1_EP_DR.2
SCK: J1.13; also elsewhere on the board
SCL: IC2.C1 (SCL), U3.7 (SCL); also elsewhere on the board
SDA: IC2.B2 (SDA), U3.8 (SDA); also elsewhere on the board
VBAT: C27.1, TP_VBAT.TP, U3.2 (CELL), U3.3 (VDD); also elsewhere on the board
VBUS: C42.1, C43.1, D3.5 (VBUS), J4.A4_B9 (VBUS), J4.A9_B4 (VBUS); also elsewhere on the board

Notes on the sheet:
E-Paper Drive Circuit
E-Paper Display Connector
Fuel Gauge
USB C Connector & ESD Protection
Buttons
Haptic Driver

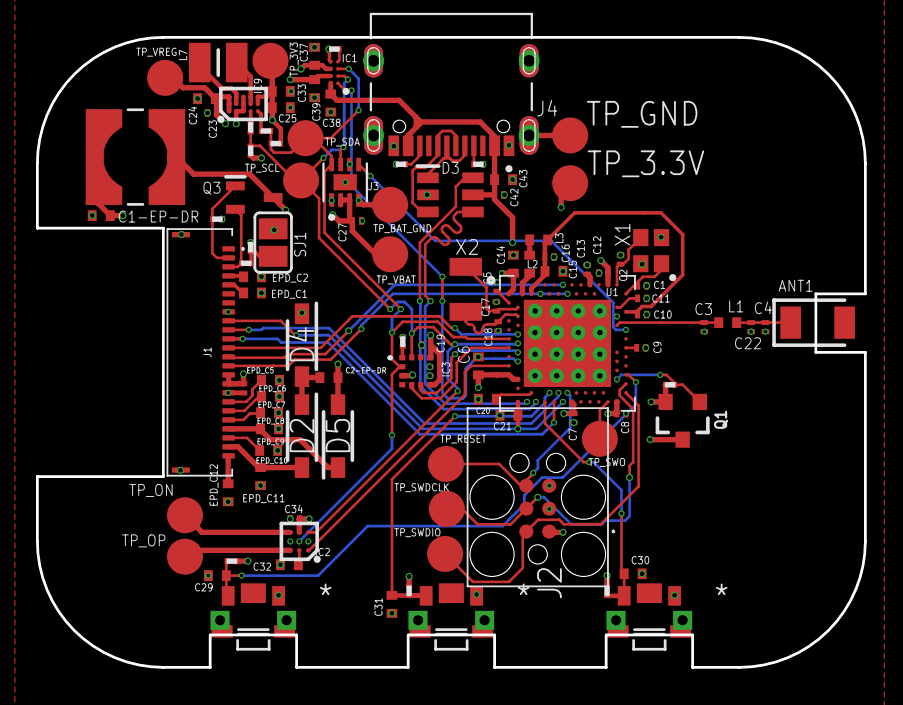
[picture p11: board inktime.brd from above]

Board: 4 copper layers, 46.0 x 35.0 mm, 105 parts (0 on the bottom side), 70 nets.

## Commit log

2026-04-10 ceva sa fie
    [inktime.brd, inktime.sch]
2026-04-14 PCB almost done
    [inktime.brd]
2026-04-15 Routing almost done
    [inktime.brd]
2026-04-17 Routing done
    [inktime.brd]
2026-04-20 Minor changes to schematic and PCB
    [inktime.brd, inktime.sch]
2026-04-20 README, manufacturing, 3D's
    [bom.csv, pnp.csv]
2026-04-22 Added schematic pdf

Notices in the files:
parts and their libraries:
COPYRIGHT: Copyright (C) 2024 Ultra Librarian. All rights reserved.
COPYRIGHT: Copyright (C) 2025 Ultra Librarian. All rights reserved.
